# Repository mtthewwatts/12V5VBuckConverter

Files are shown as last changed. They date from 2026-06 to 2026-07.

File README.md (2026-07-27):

# 12V → 5V Buck Converter

A custom KiCad-designed buck (step-down) converter PCB that regulates an 11.4V–12V LiPo battery input down to a stable 5V/5A output. Designed to power a Raspberry Pi 5 and control electronics on an autonomous line-following search-and-rescue robot, consolidating the robot's entire power system into a single battery source.

Built for **MTE 380: Mechatronics Engineering Design Workshop** at the University of Waterloo (Group 12).

## Overview

The robot this board was built for is powered by a single 3S 11.4V LiPo battery. Rather than using a separate USB power bank to run the Raspberry Pi and control electronics, this PCB steps the battery voltage down to a regulated 5V/5A rail, cutting weight and wiring complexity. Raw battery voltage still feeds the drive motors directly through a separate motor shield.

- **Input:** 8V–40V (11.4V nominal, 3S LiPo)
- **Output:** 5V regulated, up to 5A continuous
- **Topology:** Synchronous-adjacent buck converter, datasheet reference design
- **Fabrication:** 1 oz copper, ~2mm power traces sized for 25W max output, continuous ground plane

## Key ICs / Components

| Reference | Part | Description |
|---|---|---|
| IC1 | LM2679SD-5.0/NOPB | 8V–40V, 5A Step-Down Switching Regulator (Texas Instruments) |
| D1 | VS-6TQ045S-M3 | 45V, 6A Schottky Diode — D2PAK (Vishay) |

Full bill of materials is documented in [`docs/Buck_Converter_Reference.docx`](docs/Buck_Converter_Reference.docx).

## Design Notes

This design follows Texas Instruments' [SNVA054C SIMPLE SWITCHER PCB Layout Guidelines](https://www.ti.com/lit/an/snva054c/snva054c.pdf) and the [LM2679 datasheet](https://www.ti.com/lit/ds/symlink/lm2679.pdf) reference application circuit. Key layout decisions:

- **Component placement** minimizes the high-current switching loop — regulator IC, inductor, diode, and capacitors are placed tightly together to reduce parasitic inductance.
- **Routing** keeps battery input and 5V output traces short and direct to limit voltage drop, with the switching node kept compact and isolated from signal traces to reduce noise coupling.
- **Ground plane** provides a low-impedance return path for both electrical stability and thermal performance.
- **Trace widths** (~2mm on high-current paths) were sized using IPC-2221 guidelines for a 5V/5A (25W) maximum load.

See [`docs/Buck_Converter_Reference.docx`](docs/Buck_Converter_Reference.docx) for the full design rationale, and Section 2.2.3 of [`docs/Milestone8_FinalReport.docx`](docs/Milestone8_FinalReport.docx) for how this board fits into the robot's overall electrical architecture.

## Project Files

| File | Purpose |
|---|---|
| `12V5VBuckConverter.kicad_sch` | Schematic |
| `12V5VBuckConverter.kicad_pcb` | PCB layout |
| `12V5VBuckConverter.kicad_pro` | Project settings |
| `12V5VBuckConverter.step` | 3D STEP model |
| `ProjectLibrary.kicad_sym` | Project symbol library (LM2679) |
| `VS-6TQ045S-M3.kicad_sym` | Diode symbol |
| `VS6TQ045SM3.kicad_mod` | Diode footprint |
| `sym-lib-table` | Symbol library table |
| `fp-lib-table` | Footprint library table |

## Opening the Project

Open `12V5VBuckConverter.kicad_pro` in **KiCad 9.0** or later.

All custom libraries are stored in the project folder and referenced via `${KIPRJMOD}`, so no path changes are needed after cloning.

```bash
git clone https://github.com/<your-username>/<your-repo>.git
cd <your-repo>
# then open 12V5VBuckConverter.kicad_pro in KiCad
```

## Status / Known Limitations

- Validated on the bench and used successfully on Game Day, but battery voltage sag under load was not fully characterized — output behavior at low state-of-charge is a known open item.
- No onboard reverse-polarity or overcurrent protection beyond the regulator IC's internal limiting.
- Designed for a single fixed 5V/5A rail; not currently configurable for other output voltages.

## Background

This board was the electrical subsystem of a larger capstone project: a fully autonomous line-following robot built to navigate a maze, retrieve a target, and return it to a safe zone under a $300 budget and strict size/weight constraints. Full project report and results are in [`docs/Milestone8_FinalReport.docx`](docs/Milestone8_FinalReport.docx).

## License

MIT — see [LICENSE](LICENSE).

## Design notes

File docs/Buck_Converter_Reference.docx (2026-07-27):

# 12V→5V Buck Converter — Reference Document

Compiled from Group 12's MTE 380 Final Written Report (Milestone 8). All buck-converter-related design rationale, architecture, budget, testing notes, and references are collected here as a working source for future distillation.

# 1. Project Context

The robot's onboard electronics were powered by a Turnigy Bolt 2400mAh 3S 11.4V LiPo battery. A custom-designed buck converter PCB stepped this down to a regulated 5V rail to power the Raspberry Pi 5 (and associated control electronics), while the raw battery voltage fed the Adafruit Motor Shield directly for motor actuation. This consolidated power delivery into a single battery source, reducing weight and wiring complexity compared to the kit-provided USB power bank.

# 2. Power Architecture

The robot is powered by a Turnigy Bolt 2400mAh 3S 11.4V LiPo battery, which serves as the single power source for all onboard electronics and actuators. This was chosen originally to power the two DC drive motors, and the team was then able to use buck converters to use this battery to power the on board control electronics as well. This was chosen over the kit-provided USB power bank to consolidate power delivery into one source as well as reduce weight for the purposes of scoring on Game Day.

The electrical system is broken down into three subsystems — power, control, and actuation — illustrated in the report's Figures 5, 6, and 7 respectively.

As shown in the power distribution diagram (Figure 5), the 11.4V LiPo feeds into the custom buck converter PCB designed by the team, which steps the voltage down to a regulated 5V at a maximum of 5A, as well as directly into the Adafruit Motor Shield for motor actuation. The regulated 5V output powers the Raspberry Pi 5, which requires a stable 5V/5A supply in order to operate at full capacity. The webcam, mounted to the front of the chassis, draws power from the Raspberry Pi over USB.

The control diagram (Figure 6) illustrates how the Raspberry Pi communicates with the Arduino Uno over USB serial, which runs off the regulated 5V rail.

Referenced figures (not reproduced here): Figure 5 — Power wiring diagram (11.4V in red, 5V in orange, ground in black); Figure 6 — Control wiring diagram; Figure 9 — PCB buck converter CAD (left) and assembled (right); Figure 8 — Buck Converter PCB Traces Layout.

# 3. Design Trade-Off: Custom PCB vs. Off-the-Shelf Module

One key electrical design decision was the use of a custom buck converter PCB rather than an off-the-shelf voltage regulator module. While designing and manufacturing a PCB introduced additional workload in terms of circuit design, layout, and testing, it allowed for a more compact and integrated power solution.

This decision aligned with the team's objective of minimizing overall robot weight and reducing wiring complexity. Using a discrete module would have required additional connectors and mounting considerations, increasing both bulk and potential points of failure. In contrast, the custom PCB enabled direct integration into the system and cleaner power distribution.

These design decisions were informed through prior coursework, guidance from the teaching team, and additional research into switching regulator design. In particular, Texas Instruments' “Simple Switcher PCB Layout Guidelines (SNVA054C)” was used to guide layout strategy and ensure reliable operation of the converter, and was provided by Richard Yan from the Engineering Faculty.

# 4. PCB Architecture

The custom buck converter PCB was designed to step the 11.4V LiPo battery input down to a regulated 5V output capable of supplying up to 5A, required for stable operation of the Raspberry Pi 5.

The implemented circuit was based directly on the recommended application circuit from the switching regulator datasheet (LM2679SD-5.0/NOPB), selected to match the input voltage range of the LiPo battery and the required output current. Using a datasheet-proven design reduced risk and ensured the converter would operate reliably under expected loading conditions.

## 4.1 Component Logic

The PCB follows a standard buck converter topology consisting of a switching regulator IC, inductor, diode, and input/output capacitors, selected based on the reference design in the regulator datasheet.

The regulator IC controls the switching behaviour, while the inductor and capacitors smooth the output into a stable DC voltage. Input capacitors reduce voltage ripple from the battery; output capacitors ensure a stable 5V supply for the Raspberry Pi. This mirrors standard industry design practices for switching power supplies.

## 4.2 Placement Logic

Component placement was guided by best practices for switching regulator layout, particularly the need to minimize the high-current switching loop.

Key components — regulator IC, inductor, diode, and capacitors — were placed in close proximity to reduce parasitic inductance and improve efficiency. Input capacitors were positioned as close as possible to the regulator input to stabilize pulsed current draw from the battery, while output capacitors were placed near the load path.

These decisions were directly informed by the Texas Instruments layout guidelines (SNVA054C), which emphasize compact placement of the power stage to reduce noise and improve stability.

## 4.3 Routing Logic

Routing focused on minimizing resistance and maintaining clean current paths for all high-current connections. The battery input and 5V output traces were kept short and direct to reduce voltage drop and power loss.

A ground plane was implemented to provide a low-impedance return path and improve electrical stability and thermal performance. The switching node was kept compact and isolated from other traces to reduce noise coupling into signal lines.

## 4.4 Trace Width Logic

Trace widths were selected based on expected current levels and standard PCB design guidelines. The board was fabricated using 1 oz copper (approximately 35 µm thickness).

For the maximum load condition of 5V at 5A (≈25W output power), high-current traces were designed to be approximately 2mm wide, ensuring the traces can safely carry the required current while minimizing voltage drop and resistive heating.

Wider traces reduce current density, preventing overheating and improving reliability; low-current signal traces were kept narrower to conserve board space. Trace widths were determined using IPC-based trace width guidelines and verified through reference calculators.

## 4.5 Layout Implementation (KiCad)

The final PCB layout was implemented in KiCad (Figure 8), incorporating the design decisions above: wide power traces, compact switching loops, and a continuous ground plane. The layout reflects the key switching regulator layout guidelines referenced in the Texas Instruments application note.

# 5. Budget

The buck converter PCB (components + fabrication) totalled $42.99, and was the single largest contributor to the electrical subsystem cost ($89.90 total). Itemized costs below.

Item | Cost/Item | # of Items | Subtotal | Total (+HST)
DIODE SCHOTTKY 45V 6A TO263AB | $2.12 | 1 | $2.12 | $2.40
IC REG BUCK 5V 5A 14VSON | $11.42 | 1 | $11.42 | $12.90
0.47 uF Capacitor_SMD: C_0805_2012Metric | $0.30 | 1 | $0.30 | $0.34
1 nF Capacitor_SMD: C_0805_2012Metric | $0.12 | 1 | $0.12 | $0.14
0.01 uF/10,000 pF Capacitor_SMD: C_0805_2012Metric | $0.12 | 1 | $0.12 | $0.14
15 uF Capacitor_SMD: C_1210_3225Metric | $1.04 | 3 | $3.12 | $3.53
180 uF Capacitor_SMD: CP_Elec_8x10 | $2.90 | 2 | $5.80 | $6.55
Red LED 0805_2012 Metric | $0.25 | 1 | $0.25 | $0.28
Blue LED 0805_2012 Metric | $0.31 | 1 | $0.31 | $0.35
Phoenix Terminal Blocks SMD 2P 5.08mm | $1.92 | 1 | $1.92 | $2.17
Phoenix Terminal Blocks SMD 4P 5.08mm | $3.64 | 1 | $3.64 | $4.11
22uH Inductor SMD L7.3x7.3 mm | $1.49 | 1 | $1.49 | $1.68
5.6k Resistor SMD 0805_2012Metric | $0.15 | 3 | $0.45 | $0.51
1.5k Resistor SMD 0805_2012Metric | $0.15 | 1 | $0.15 | $0.17
0.01 ohms Resistor SMD 2512_6332Metric | $0.75 | 1 | $0.75 | $0.85
Wago, SPLICE LEVER 24-12AWG 3POS | $1.63 | 2 | $3.26 | $3.68
PCB Board Cost | $6.09 | 1 | $6.09 | $6.88
Buck Converter PCB Total | | | | $42.99

# 6. Schedule Notes

The scope of the PCB was reduced (to power distribution only) as part of the team's recovery plan after falling behind schedule during reading/midterm week. The PCB was further delayed relative to other subsystems by procurement requirements and design rework due to its narrowed scope.

The power delivery PCB was ordered and assembled in time to be used for Game Day, reducing the weight of the robot by 200 grams (relative to the kit-provided USB power bank approach).

# 7. Testing, Performance & Lessons Learned

Power delivery caused some inconsistencies during testing. After switching to the team's custom buck converter PCB for Raspberry Pi and motor power (from a single LiPo battery), the battery drained much faster than expected. As the voltage dropped, the robot's behavior changed as well — particularly in motor response and stability. The system performed differently depending on battery charge level, which made testing less consistent and difficult to tune.

The physical layout also created practical challenges: the battery was mounted at the bottom of the stacked plate chassis, so accessing it required disassembling most of the structure, slowing down testing and iteration, especially when swapping in a fresh battery.

# 8. Recommendation Arising From This Subsystem

A redesigned chassis with an easy-to-access slot to store the LiPo battery would allow for faster switches during the extensive testing and tuning phase of the project. Many batteries were drained during the iterative software tuning process, and making the robot easier to service would save at least 5 hours of disassembly and reassembly throughout the project.

# 9. References Used for This Subsystem

[2] Texas Instruments, "AN-1229 SIMPLE SWITCHER® PCB Layout Guidelines," April 2013. Available: https://www.ti.com/lit/an/snva054c/snva054c.pdf

[3] Texas Instruments, "LM2679 SIMPLE SWITCHER® 5-A Step-Down Voltage Regulator," June 2016. Available: https://www.ti.com/lit/ds/symlink/lm2679.pdf

[4] P. Ghosh, "IPC-2221 Circuit Board Design," Sierra Circuits Proto Express, 30 January 2023. Available: https://www.protoexpress.com/blog/ipc-2221-circuit-board-design/

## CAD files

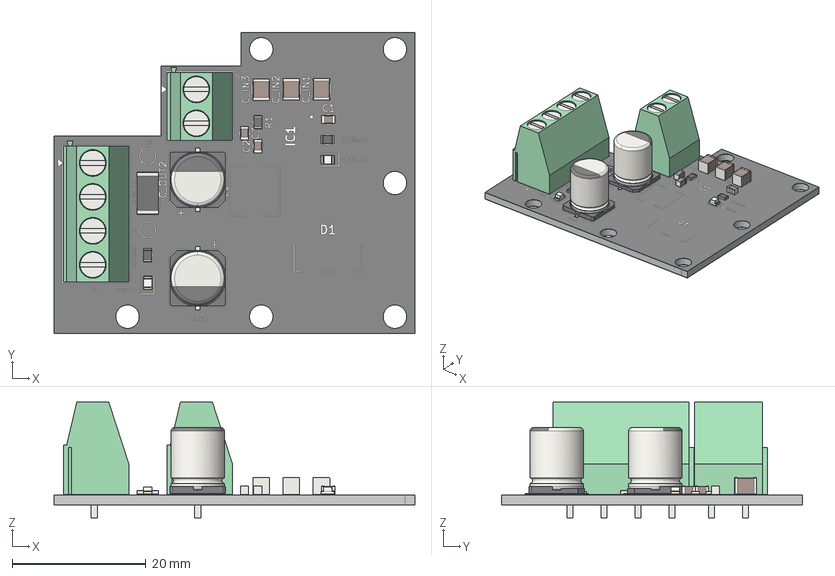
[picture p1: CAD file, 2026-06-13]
12V5VBuckConverter.step
54.0 x 45.0 x 17.3 mm
C_1210_3225Metric x 3
C_0805_2012Metric x 3
R_0805_2012Metric x 3
LED_0805_2012Metric x 2
CP_Elec_8x10 x 2
R_2512_6332Metric
TerminalBlock_Phoenix_MKDS-1,5-4-5.08_1x04_P5.08mm_Horizontal
TerminalBlock_Phoenix_MKDS-1,5-2-5.08_1x02_P5.08mm_Horizontal
MTE380 PCB - First Draft_silkscreen
MTE380 PCB - First Draft_soldermask
MTE380 PCB - First Draft_PCB

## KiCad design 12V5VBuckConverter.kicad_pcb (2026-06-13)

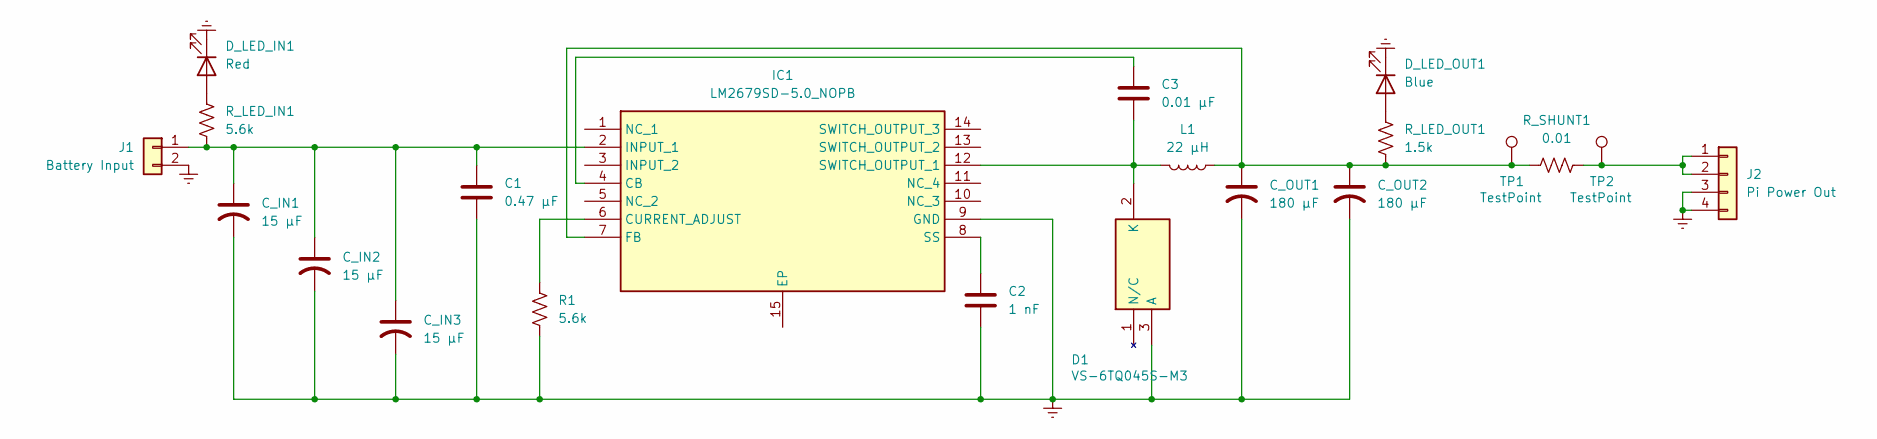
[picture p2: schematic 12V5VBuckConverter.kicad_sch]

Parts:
C1: 0.47 μF; C_0805_2012Metric
C2: 1 nF; C_0805_2012Metric
C3: 0.01 μF; C_0805_2012Metric
C_IN1, C_IN2, C_IN3: 15 μF; C_1210_3225Metric
C_OUT1, C_OUT2: 180 μF; CP_Elec_8x10
D1: VS-6TQ045S-M3; VS6TQ045SM3; Mouser Part Number 78-VS-6TQ045S-M3
D_LED_IN1: Red; LED_0805_2012Metric
D_LED_OUT1: Blue; LED_0805_2012Metric
IC1: LM2679SD-5.0_NOPB; SON80P500X600X100-15N; Mouser Part Number 926-LM2679SD50NOPB
J1: Battery Input; TerminalBlock_Phoenix_MKDS-1,5-2-5.08_1x02_P5.08mm_Horizont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
J2: Pi Power Out; TerminalBlock_Phoenix_MKDS-1,5-4-5.08_1x04_P5.08mm_Horizont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
L1: 22 μH; L_7.3x7.3_H4.5
R1: 5.6k; R_0805_2012Metric
R_LED_IN1: 5.6k; R_0805_2012Metric
R_LED_OUT1: 1.5k; R_0805_2012Metric
R_SHUNT1: 0.01; R_2512_6332Metric
TP1, TP2: TestPoint; TestPoint_Pad_D2.0mm

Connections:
GND\: C1.2, C2.2, C_IN1.2, C_IN2.2, C_IN3.2, C_OUT1.2, C_OUT2.2, D1.3 (A), D_LED_IN1.1 (K), D_LED_OUT1.1 (K), IC1.9 (GND), IC1.15 (EP), J1.2, J2.3, J2.4, R1.2
unnamed: C3.2, D1.2 (K), IC1.12 (SWITCH_OUTPUT_1), L1.2
unnamed: D_LED_IN1.2 (A), R_LED_IN1.1
unnamed: D_LED_OUT1.2 (A), R_LED_OUT1.1
unnamed: C3.1, IC1.4 (CB)
unnamed: IC1.6 (CURRENT_ADJUST), R1.1
unnamed: C_OUT1.1, C_OUT2.1, IC1.7 (FB), L1.1, R_LED_OUT1.2, R_SHUNT1.1, TP1.1
unnamed: C1.1, C_IN1.1, C_IN2.1, C_IN3.1, IC1.2 (INPUT_1), J1.1, R_LED_IN1.2
unnamed: C2.1, IC1.8 (SS)
unnamed: J2.1, J2.2, R_SHUNT1.2, TP2.1

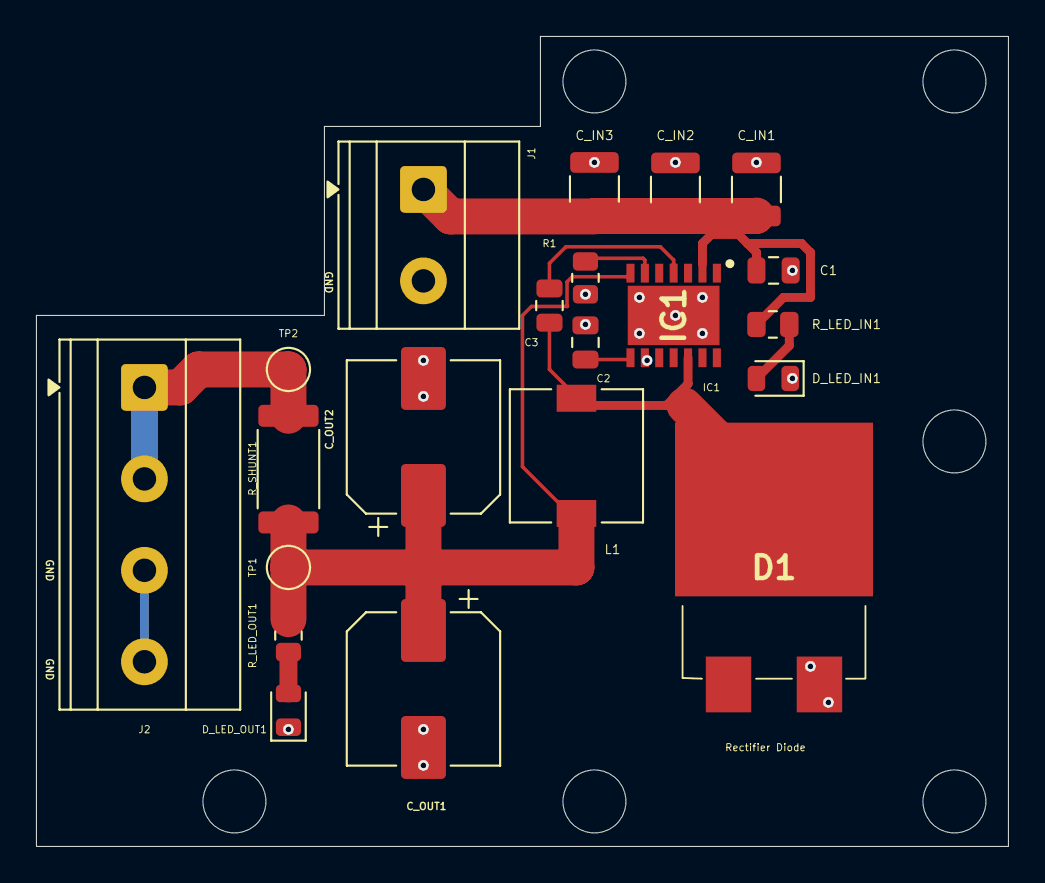
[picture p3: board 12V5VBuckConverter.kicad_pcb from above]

Board: 2 copper layers, 54.0 x 45.0 mm, 27 parts (0 on the bottom side), 10 nets.

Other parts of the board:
MH1, MH2, MH3, MH4, MH5, MH6: MountingHole_3mm
